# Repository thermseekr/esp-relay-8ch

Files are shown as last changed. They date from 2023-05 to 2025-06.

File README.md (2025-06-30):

# ESP-RELAY-8CH

ESP32 based board with 8x 24 VDC inputs and 8x 10A relay outputs.

This board is designed to be controlled by an Olimex ESP32-POE or ESP32-POE-ISO modules.

The dimensions are such that the board can be mounted on a PCB DIN rail holder from the Brazilian manufacturer Metaltex, check [here](https://www.metaltex.com.br/produtos/componentes/suportes/sp7-suporte-para-montagem-de-placa-de-circuito-impresso-em-trilho-din) for details.

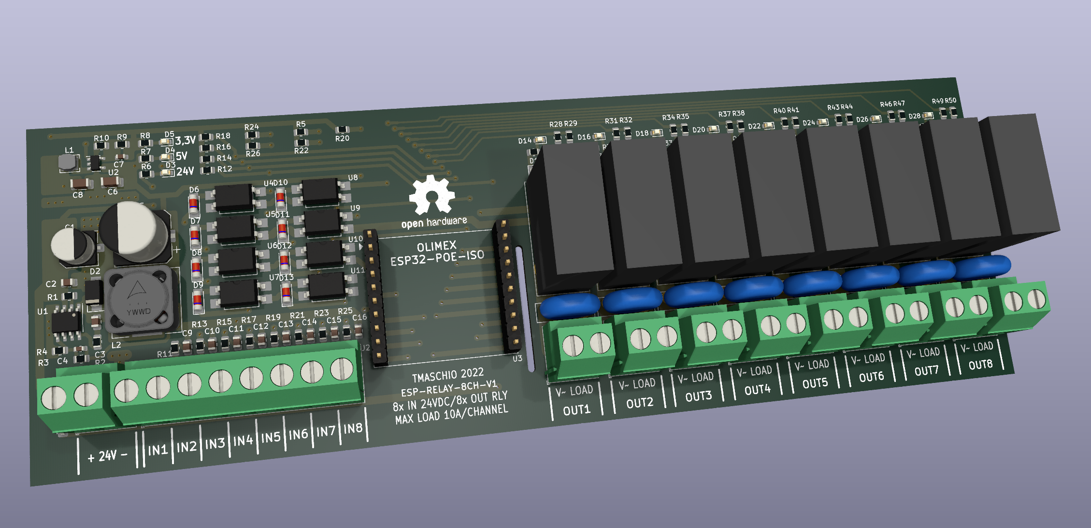
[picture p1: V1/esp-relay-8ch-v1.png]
ESP-RELAY-8CH


## LICENSE

This project is licensed under the [Creative Commons BY-NC 4.0 License](https://creativecommons.org/licenses/by-nc/4.0/).
Commercial use is not permitted without prior written consent. See the [LICENSE.txt](LICENSE.txt) file for details.

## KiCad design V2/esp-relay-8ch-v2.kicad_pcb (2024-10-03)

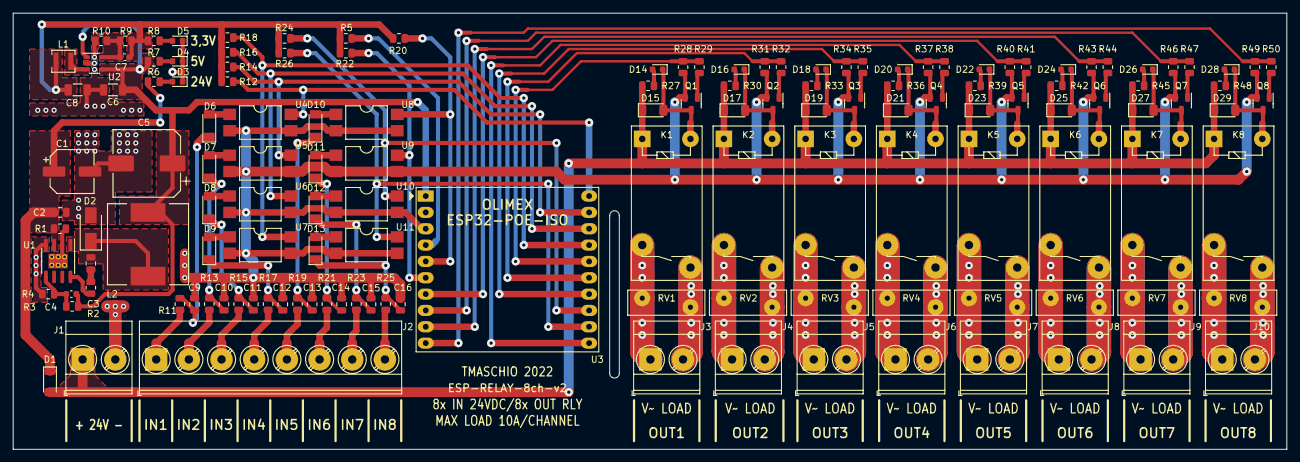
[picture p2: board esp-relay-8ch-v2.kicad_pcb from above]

Board: 2 copper layers, 198.0 x 67.8 mm, 142 parts (0 on the bottom side), 96 nets.

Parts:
C1: 47uF/35V/6,3x5,4; CP_Elec_6.3x5.4
C2, C3: 0,1uF/50V/0805; C_0805_2012Metric
C4: 12pF/50V/0603; C_0603_1608Metric
C5: 470uF/16V/10x10; CP_Elec_10x10
C6, C8: 10uF/16V/1206; C_1206_3216Metric
C7: 22pF/50V/0603; C_0603_1608Metric
C9, C10, C11, C12, C13, C14, C15, C16: 33nF/50V/0805; C_0805_2012Metric
D1: SM4007PL/SOD-123; D_SOD-123
D2: SS510; D_SMA
D3, D4, D5, D14, D16, D18, D20, D22, D24, D26, D28: BLUE/0603; LED_0603_1608Metric
D6, D7, D8, D9, D10, D11, D12, D13: 9V1/500mW; D_MiniMELF
D15, D17, D19, D21, D23, D25, D27, D29: 1N4148/SOD-123; D_SOD-123
J1: +24VDC; TerminalBlock_Phoenix_MKDS-3-2-5.08_1x02_P5.08mm_Horizontal
J2: INPUTS; TerminalBlock_Phoenix_MKDS-3-8-5.08_1x08_P5.08mm_Horizontal
J3: OUT1; TerminalBlock_Phoenix_MKDS-3-2-5.08_1x02_P5.08mm_Horizontal
J4: OUT2; TerminalBlock_Phoenix_MKDS-3-2-5.08_1x02_P5.08mm_Horizontal
J5: OUT3; TerminalBlock_Phoenix_MKDS-3-2-5.08_1x02_P5.08mm_Horizontal
J6: OUT4; TerminalBlock_Phoenix_MKDS-3-2-5.08_1x02_P5.08mm_Horizontal
J7: OUT5; TerminalBlock_Phoenix_MKDS-3-2-5.08_1x02_P5.08mm_Horizontal
J8: OUT6; TerminalBlock_Phoenix_MKDS-3-2-5.08_1x02_P5.08mm_Horizontal
J9: OUT7; TerminalBlock_Phoenix_MKDS-3-2-5.08_1x02_P5.08mm_Horizontal
J10: OUT8; TerminalBlock_Phoenix_MKDS-3-2-5.08_1x02_P5.08mm_Horizontal
K1, K2, K3, K4, K5, K6, K7, K8: G5PZ-1A; Relay_SPST_Omron-G5PZ-1A
L1: 2,2uH 1,5A; L_3x3_H1.5
L2: 33uH 2,1A; L_12x12mm_H6mm
Q1, Q2, Q3, Q4, Q5, Q6, Q7, Q8: MMBT2222A/SOT-23-3; SOT-23
R1: 30mR/0,250W/0805; R_0805_2012Metric
R2: 5R1/0,125W/0805; R_0805_2012Metric
R3: 300k/0,125W/0805; R_0805_2012Metric
R4: 57,6k/0,125W/0805; R_0805_2012Metric
R5, R27, R30, R33, R36, R39, R42, R45, R48: 4k7/0,125W/0805; R_0805_2012Metric
R6: 5k6/0,125W/0805; R_0805_2012Metric
R7: 820R/0,125W/0805; R_0805_2012Metric
R8: 330R/0,125W/0805; R_0805_2012Metric
R9: 100k/0,125W/0805; R_0805_2012Metric
R10: 22,1k/0,125W/0805; R_0805_2012Metric
R11, R13, R15, R17, R19, R21, R23, R25: 1k2/0,125W/0805; R_0805_2012Metric
R12, R14, R16, R18, R20, R22, R24, R26: 3k3/0,125W/0805; R_0805_2012Metric
R28, R31, R34, R37, R40, R43, R46, R49: 10k/0,125W/0805; R_0805_2012Metric
R29, R32, R35, R38, R41, R44, R47, R50: 1k/0,125W/0805; R_0805_2012Metric
RV1, RV2, RV3, RV4, RV5, RV6, RV7, RV8: 250VAC; RV_Disc_D12mm_W3.9mm_P7.5mm
U1: TX4138; SOIC-8-1EP_3.9x4.9mm_P1.27mm_EP2.29x3mm_ThermalVias
U2: SY8089A1AAC; TSOT-23-5
U3: Olimex_ESP32-POE; Olimex_ESP32-POE_Pads
U4, U5, U6, U7, U8, U9, U10, U11: LTV-817S; SMDIP-4_W9.53mm

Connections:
+3.3V: C7.1, C8.1, L1.2, R5.1, R8.1, R9.1, R12.1, R14.1, R16.1, R18.1, R20.1, R22.1, R24.1, R26.1
+5V: C4.1, C5.1, C6.1, L2.2, R3.1, R7.1, U2.1 (EN), U2.4 (IN), U3.1 (5V)
+24V: D1.2 (A), D15.1 (K), D17.1 (K), D19.1 (K), D21.1 (K), D23.1 (K), D25.1 (K), D27.1 (K), D29.1 (K), J1.1, K1.1, K2.1, K3.1, K4.1, K5.1, K6.1, K7.1, K8.1, R27.1, R30.1, R33.1, R36.1, R39.1, R42.1, R45.1, R48.1
+VReg: C1.1, C2.1, D1.1 (K), R1.1, R6.1, U1.3 (VIN)
GNDREF: C1.2, C2.2, C5.2, C6.2, C8.2, C9.2, C10.2, C11.2, C12.2, C13.2, C14.2, C15.2, C16.2, D2.2 (A), D3.1 (K), D4.1 (K), D5.1 (K), J1.2, Q1.2 (E), Q2.2 (E), Q3.2 (E), Q4.2 (E), Q5.2 (E), Q6.2 (E), Q7.2 (E), Q8.2 (E), R4.2, R10.2, R28.2, R31.2, R34.2, R37.2, R40.2, R43.2, R46.2, R49.2, U1.4 (GND), U2.2 (GND), U3.3 (GND), U4.2, U4.3, U5.2, U5.3, U6.2, U6.3, U7.2, U7.3, U8.2, U8.3, U9.2, U9.3, U10.2, U10.3, U11.2, U11.3
IN1: R12.2, U3.20 (GPI39), U4.4
IN2: R14.2, U3.19 (GPI36\U1RXD), U5.4
IN3: R16.2, U3.18 (GPI35), U6.4
IN4: R18.2, U3.17 (GPI34\BUT1), U7.4
IN5: R20.2, U3.5 (GPIO0), U8.4
IN6: R22.2, U3.6 (GPIO1\U0TXD), U9.4
IN7: R24.2, U3.13 (GPIO15\HS2_CMD), U10.4
IN8: R26.2, U3.12 (GPIO14\HS2_CLK), U11.4
unnamed: C3.1, R2.1
unnamed: C3.2, D2.1 (K), L2.1, U1.1 (SW)
unnamed: C4.2, R3.2, R4.1, U1.5 (FB)
unnamed: C7.2, R9.2, R10.1, U2.5 (FB)
unnamed: C9.1, D6.1 (K), R11.1
unnamed: C10.1, D7.1 (K), R13.1
unnamed: C11.1, D8.1 (K), R15.1
unnamed: C12.1, D9.1 (K), R17.1
unnamed: C13.1, D10.1 (K), R19.1
unnamed: C14.1, D11.1 (K), R21.1
unnamed: C15.1, D12.1 (K), R23.1
unnamed: C16.1, D13.1 (K), R25.1
unnamed: D3.2 (A), R6.2
unnamed: D4.2 (A), R7.2
unnamed: D5.2 (A), R8.2
unnamed: D6.2 (A), U4.1
unnamed: D7.2 (A), U5.1
unnamed: D8.2 (A), U6.1
unnamed: D9.2 (A), U7.1
unnamed: D10.2 (A), U8.1
unnamed: D11.2 (A), U9.1
unnamed: D12.2 (A), U10.1
unnamed: D13.2 (A), U11.1
unnamed: D14.1 (K), D15.2 (A), K1.4, Q1.3 (C)
unnamed: D14.2 (A), R27.2
unnamed: D16.1 (K), D17.2 (A), K2.4, Q2.3 (C)
unnamed: D16.2 (A), R30.2
unnamed: D18.1 (K), D19.2 (A), K3.4, Q3.3 (C)
unnamed: D18.2 (A), R33.2
unnamed: D20.1 (K), D21.2 (A), K4.4, Q4.3 (C)
unnamed: D20.2 (A), R36.2
unnamed: D22.1 (K), D23.2 (A), K5.4, Q5.3 (C)
unnamed: D22.2 (A), R39.2
unnamed: D24.1 (K), D25.2 (A), K6.4, Q6.3 (C)
unnamed: D24.2 (A), R42.2
unnamed: D26.1 (K), D27.2 (A), K7.4, Q7.3 (C)
unnamed: D26.2 (A), R45.2
unnamed: D28.1 (K), D29.2 (A), K8.4, Q8.3 (C)
unnamed: D28.2 (A), R48.2
unnamed: J2.1, R11.2
unnamed: J2.2, R13.2
unnamed: J2.3, R15.2
unnamed: J2.4, R17.2
unnamed: J2.5, R19.2
unnamed: J2.6, R21.2
unnamed: J2.7, R23.2
unnamed: J2.8, R25.2
unnamed: J3.1, K1.2, RV1.1
unnamed: J3.2, K1.3, RV1.2
unnamed: J4.1, K2.2, RV2.1
unnamed: J4.2, K2.3, RV2.2
unnamed: J5.1, K3.2, RV3.1
unnamed: J5.2, K3.3, RV3.2
unnamed: J6.1, K4.2, RV4.1
unnamed: J6.2, K4.3, RV4.2
unnamed: J7.1, K5.2, RV5.1
unnamed: J7.2, K5.3, RV5.2
unnamed: J8.1, K6.2, RV6.1
unnamed: J8.2, K6.3, RV6.2
unnamed: J9.1, K7.2, RV7.1
unnamed: J9.2, K7.3, RV7.2
unnamed: J10.1, K8.2, RV8.1
unnamed: J10.2, K8.3, RV8.2
unnamed: L1.1, U2.3 (LX)
unnamed: Q1.1 (B), R29.1
unnamed: Q2.1 (B), R32.1
unnamed: Q3.1 (B), R35.1
unnamed: Q4.1 (B), R38.1
unnamed: Q5.1 (B), R41.1
unnamed: Q6.1 (B), R44.1
unnamed: Q7.1 (B), R47.1
unnamed: Q8.1 (B), R50.1
unnamed: R1.2, U1.2 (ILIM), U1.9 (ILIM)
unnamed: R2.2, U1.8 (BS)
unnamed: R5.2, U3.4 (ESP_EN)
OUT1: R28.1, R29.2, U3.16 (GPIO33)
OUT2: R31.1, R32.2, U3.15 (GPIO32)
OUT3: R34.1, R35.2, U3.14 (GPIO16\I2C-SCL)
OUT4: R37.1, R38.2, U3.11 (GPIO13\I2C-SDA)
OUT5: R40.1, R41.2, U3.7 (GPIO2\HS2\DATA0)
OUT6: R43.1, R44.2, U3.9 (GPIO4\U1TXD)
OUT7: R46.1, R47.2, U3.8 (GPIO3\U0RXD)
OUT8: R49.1, R50.2, U3.10 (GPIO5\SPI_CS)

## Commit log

2022-10-11 SCH and PCB updates
    [ESP-relay-8ch-V1.kicad_pcb, ESP-relay-8ch-V1.kicad_sch]
2022-10-11 SCH and PCB development
    [ESP-relay-8ch-V1.kicad_pcb, ESP-relay-8ch-V1.kicad_sch]
2022-10-14 SCH tweaks
    [ESP-relay-8ch-V1.kicad_pcb, ESP-relay-8ch-V1.kicad_sch]
2022-10-17 Removed V2
    [ESP-relay-8ch-V2.kicad_pcb, ESP-relay-8ch-V2.kicad_sch, esp32.kicad_sch]
2022-10-19 PCB updates
    [ESP-relay-8ch-V1.kicad_pcb, ESP-relay-8ch-V1.kicad_sch]
2022-10-21 JLCPCB part update
    [ESP-relay-8ch-V1.kicad_pcb, ESP-relay-8ch-V1.kicad_sch]
2023-04-26 Can't remember!
    [ESP-relay-8ch-V1.kicad_pcb, ESP-relay-8ch-V1.kicad_sch]
2023-05-21 Update board images
2023-05-21 Update board image files.
2023-09-02 Design optimization
    [ESP-relay-8ch-V1.kicad_pcb, ESP-relay-8ch-V1.kicad_sch]
2023-09-06 Rename to lowercase
    [small-esp-relay-8ch-v1.kicad_pcb, small-esp-relay-8ch-v1.kicad_sch]
2023-09-22 New V2
    [esp-relay-8ch-v2-inputs.kicad_sch, esp-relay-8ch-v2-outputs.kicad_sch, esp-relay-8ch-v2.kicad_pcb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]
2023-09-23 V2 design
    [esp-relay-8ch-v2-outputs.kicad_sch, esp-relay-8ch-v2.kicad_sch]
2024-10-03 Update to Kicad 8
    [esp-relay-8ch-v2-inputs.kicad_sch, esp-relay-8ch-v2-outputs.kicad_sch, esp-relay-8ch-v2.kicad_pcb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]
